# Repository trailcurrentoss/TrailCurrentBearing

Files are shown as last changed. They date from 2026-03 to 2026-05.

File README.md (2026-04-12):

# TrailCurrent Bearing

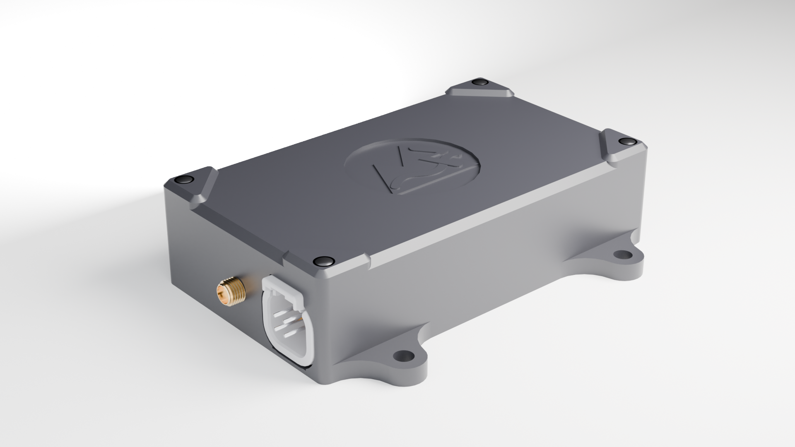
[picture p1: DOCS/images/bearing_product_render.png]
TrailCurrent Bearing


GNSS (Global Navigation Satellite System) module for precise positioning, timing, and navigation. Part of the [TrailCurrent](https://trailcurrent.com) open-source vehicle platform.

## Project Overview

TrailCurrent Bearing is a standalone GNSS module that reads data from a DFRobot Gravity GNSS receiver via I2C and distributes it over the CAN bus for other modules to consume.

**Example Use Cases:**
- Digital clocks with precise time synchronization
- Navigation and geolocation devices
- Geospatial macros that control devices based on pinned locations
- Vehicle tracking and positioning systems

## Hardware Overview

- **Microcontroller:** ESP32-S3 (Waveshare ESP32-S3-RS485-CAN board)
- **GNSS Receiver:** DFRobot Gravity GNSS (I2C, multi-constellation)
- **CAN Bus:** 500 kbps via TWAI driver (GPIO 15 TX, GPIO 16 RX)
- **I2C:** GPIO 1 SDA, GPIO 2 SCL
- **Flash:** 4 MB with dual OTA partitions

### Components

- DFRobot Gravity GNSS module (GPS + BeiDou + GLONASS)
- Waveshare ESP32-S3-RS485-CAN module
- JST XH connectors for power and signal distribution

### KiCAD Library Dependencies

This project uses the consolidated [TrailCurrentKiCADLibraries](https://github.com/trailcurrentoss/TrailCurrentKiCADLibraries).

**Setup:**

```bash
# Clone the library
git clone git@github.com:trailcurrentoss/TrailCurrentKiCADLibraries.git

# Set environment variables (add to ~/.bashrc or ~/.zshrc)
export TRAILCURRENT_SYMBOL_DIR="/path/to/TrailCurrentKiCADLibraries/symbols"
export TRAILCURRENT_FOOTPRINT_DIR="/path/to/TrailCurrentKiCADLibraries/footprints"
export TRAILCURRENT_3DMODEL_DIR="/path/to/TrailCurrentKiCADLibraries/3d_models"
```

See [KICAD_ENVIRONMENT_SETUP.md](https://github.com/trailcurrentoss/TrailCurrentKiCADLibraries/blob/main/KICAD_ENVIRONMENT_SETUP.md) for detailed setup instructions.

## Firmware

Built with ESP-IDF (v5.5.x). Pure C, no Arduino framework.

### Prerequisites

```bash
# Install ESP-IDF (one-time setup)
# See https://docs.espressif.com/projects/esp-idf/en/stable/esp32/get-started/

# Source the ESP-IDF environment
source ~/esp/v5.5.2/esp-idf/export.sh
```

### Build and Flash

```bash
idf.py set-target esp32s3
idf.py build
idf.py -p /dev/ttyACM0 flash monitor
```

### Release Binaries

The firmware produces two binary types for different deployment methods:

| Binary | Purpose | How it's used |
|---|---|---|
| `bearing.bin` | App-only image | OTA updates via Headwaters (`esp_ota_write` validates the app header) |
| `bearing_merged.bin` | Full flash image (bootloader + partition table + OTA data + app) | Web flasher (writes entire flash at offset 0x0) |

After building, run the merge script to create both:

```bash
idf.py build
./merge.sh
```

Attach **both** files to each GitHub release. The merged binary cannot be used for OTA — `esp_ota_end()` validates an app image header, and the merged binary starts with the bootloader, which would fail validation.

### OTA Firmware Update

Firmware can be updated over-the-air via the CAN bus trigger protocol:

1. Send CAN ID `0x00` with the target device's last 3 MAC bytes
2. The device joins WiFi (credentials must be provisioned first) and starts an HTTP server
3. Upload the **app-only** firmware binary:

```bash
curl -X POST http://esp32-XXYYZZ.local/ota --data-binary @build/bearing.bin
```

The device writes to the inactive OTA partition and reboots with the new firmware. If the upload fails or times out (3 minutes), the device returns to normal operation.

### mDNS Self-Discovery

When CAN ID `0x02` is broadcast (typically by the Headwaters controller), all modules with WiFi credentials join the network and advertise themselves via mDNS:

- **Service:** `_trailcurrent._tcp`
- **TXT Records:**
  - `type=bearing` — module type
  - `canid=0x06` — primary CAN status message ID
  - `fw=<version>` — firmware version

The Headwaters controller queries mDNS to discover all online modules, then confirms each via `GET /discovery/confirm`. Modules disconnect from WiFi and return to CAN-only operation after confirmation or a 3-minute timeout.

## CAN Bus Protocol

All messages use standard (11-bit) identifiers at 500 kbps.

### Graceful Node Management

The CAN bus uses a TX_ACTIVE / TX_PROBING state machine that allows nodes to enter and leave the bus without impacting other nodes:

- **TX_ACTIVE:** Normal operation at 30 Hz. If 3 consecutive TX failures occur (no ACK from peers), transitions to TX_PROBING.
- **TX_PROBING:** Sends a single status message every 2 seconds. When a peer ACKs a transmission or incoming RX data is detected, transitions back to TX_ACTIVE.

This means unplugging a module causes it to gracefully back off, and plugging it back in resumes full-rate communication automatically with zero configuration.

### TX Messages (GNSS Data)

| ID | Name | DLC | Format |
|----|---|-----|---|
| `0x06` | DateTime | 7 | `[year_H, year_L, month, day, hour, minute, second]` |
| `0x07` | SatSpeedCourse | 6 | `[satellites, speed_H, speed_L, course_H, course_L, gnss_mode]` |
| `0x08` | Altitude | 4 | `[alt_3, alt_2, alt_1, alt_0]` — altitude in meters * 100 |
| `0x09` | LatLon | 8 | `[lat_sign, lat_2, lat_1, lat_0, lon_sign, lon_2, lon_1, lon_0]` — degrees * 10000 |

**Encoding details:**
- **Speed:** knots * 100 (uint16, big-endian)
- **Course:** degrees * 10 (uint16, big-endian, rounded)
- **Altitude:** meters * 100 (uint32, big-endian)
- **Lat/Lon:** sign byte (0=positive, 1=negative) + 24-bit scaled value (degrees * 10000)

### RX Messages (Control)

| ID | Name | Purpose |
|----|---|---|
| `0x00` | OTA Trigger | `[mac0, mac1, mac2]` — target device by last 3 MAC bytes |
| `0x01` | WiFi Config | Chunked credential provisioning (see below) |
| `0x02` | Discovery | Broadcast trigger for mDNS self-discovery |
| `0x04` | Version Report | Sent on boot: `[mac3, mac4, mac5, major, minor, patch]` — reports running firmware version to Headwaters |

### WiFi Credential Provisioning (CAN ID 0x01)

WiFi credentials are sent in 6-byte chunks over CAN:

1. **Start:** `[0x01, ssid_len, pass_len, ssid_chunks, pass_chunks]`
2. **SSID chunks:** `[0x02, chunk_index, byte0..byte5]`
3. **Password chunks:** `[0x03, chunk_index, byte0..byte5]`
4. **End:** `[0x04, xor_checksum]`

Each chunk carries up to 6 bytes. A 5-second timeout resets reception if a chunk is missed.

## GNSS Modes

The DFRobot Gravity receiver supports multiple satellite constellation configurations:

| Mode | Constellations |
|---|---|
| 1 | GPS only |
| 2 | BeiDou only |
| 3 | GPS + BeiDou |
| 4 | GLONASS only |
| 5 | GPS + GLONASS |
| 6 | BeiDou + GLONASS |
| 7 | GPS + BeiDou + GLONASS (default) |

## Project Structure

```
main/                       # ESP-IDF firmware
├── main.c                  # GNSS polling, CAN TX/RX with state machine
├── gnss.h / gnss.c         # DFRobot GNSS I2C driver
├── ota.h / ota.c           # OTA updates & WiFi provisioning
├── discovery.h / discovery.c  # mDNS auto-discovery
├── CMakeLists.txt          # Build config
└── idf_component.yml       # Managed dependencies (mdns)

EDA/                        # KiCAD hardware design
├── trailcurrent-gps-module.kicad_pro
├── trailcurrent-gps-module.kicad_sch  # Root schematic (5 sheets)
├── trailcurrent-gps-module.kicad_pcb
├── mcu.kicad_sch           # MCU subsystem
├── power.kicad_sch         # Power management
├── can.kicad_sch           # CAN interface
└── connectivity.kicad_sch  # GNSS interface

CAD/                        # FreeCAD housing / 3D prints
partitions.csv              # Dual OTA partition table
sdkconfig.defaults          # Build defaults
```

## Manufacturing

- **PCB Files:** Ready for fabrication via standard PCB services (JLCPCB, OSH Park, etc.)
- **BOM Generation:** Export BOM from KiCAD schematic (Tools > Generate BOM)
- **JLCPCB Assembly:** See [BOM_ASSEMBLY_WORKFLOW.md](https://github.com/trailcurrentoss/TrailCurrentKiCADLibraries/blob/main/BOM_ASSEMBLY_WORKFLOW.md)

## License

MIT License - See LICENSE file for details

This is open source hardware. You are free to use, modify, and distribute these designs for personal or commercial purposes.

## Contributing

Improvements and contributions are welcome! Please submit issues or pull requests to the main repository.

## Support

For questions about:
- **KiCAD setup:** See [KICAD_ENVIRONMENT_SETUP.md](https://github.com/trailcurrentoss/TrailCurrentKiCADLibraries/blob/main/KICAD_ENVIRONMENT_SETUP.md)
- **Library consolidation:** See [CONNECTOR_CONSOLIDATION_SUMMARY.md](https://github.com/trailcurrentoss/TrailCurrentKiCADLibraries/blob/main/CONNECTOR_CONSOLIDATION_SUMMARY.md)
- **Assembly workflow:** See [BOM_ASSEMBLY_WORKFLOW.md](https://github.com/trailcurrentoss/TrailCurrentKiCADLibraries/blob/main/BOM_ASSEMBLY_WORKFLOW.md)

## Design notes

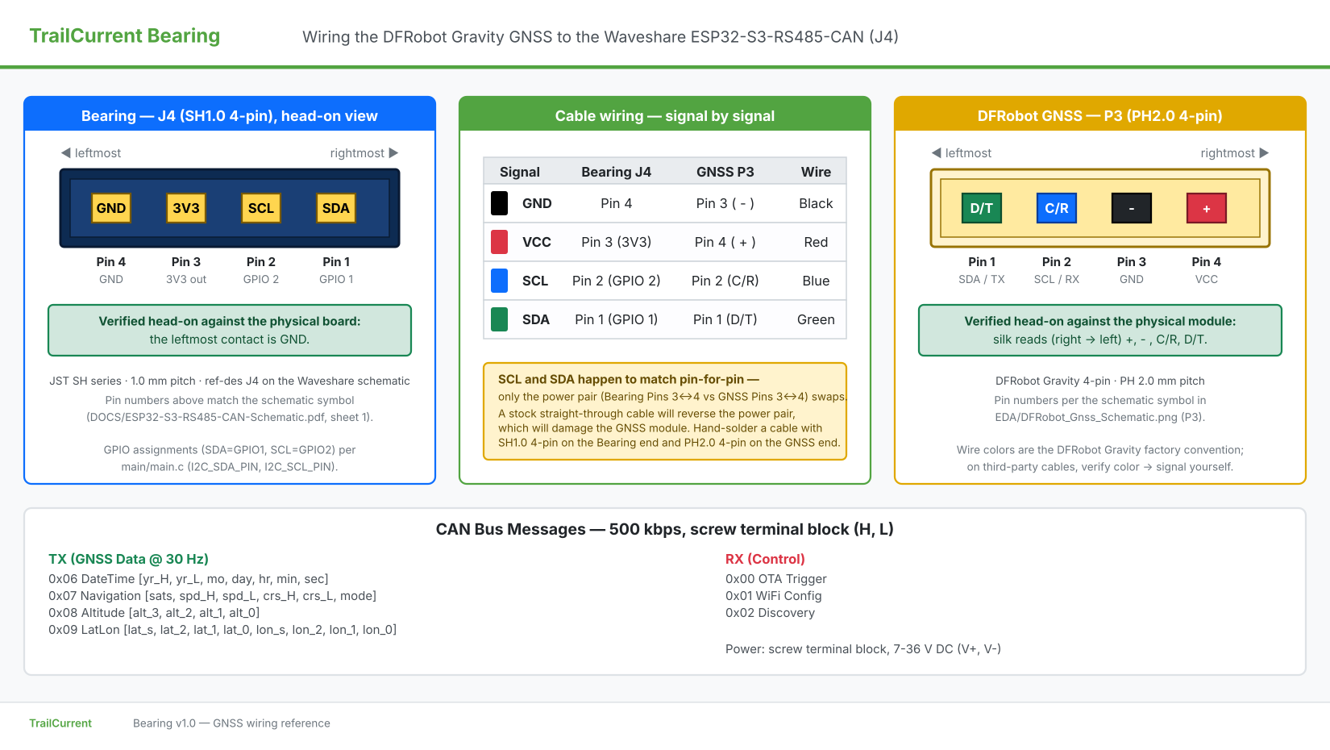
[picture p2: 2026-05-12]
DOCS/bearing-pinout.png

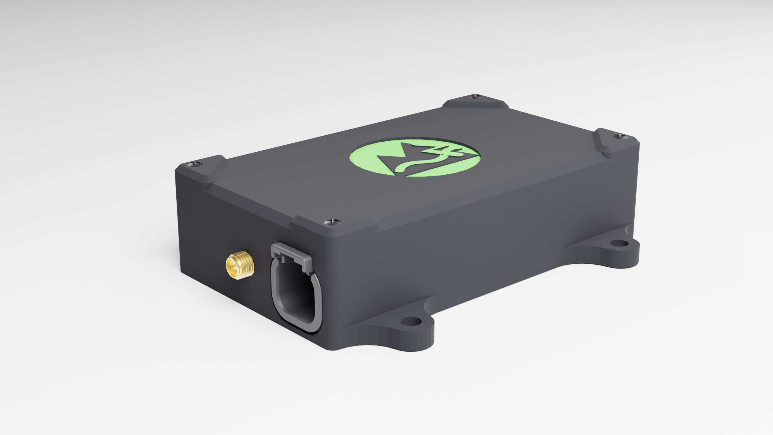
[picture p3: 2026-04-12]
CAD/TrailCurrentBearingRender.png

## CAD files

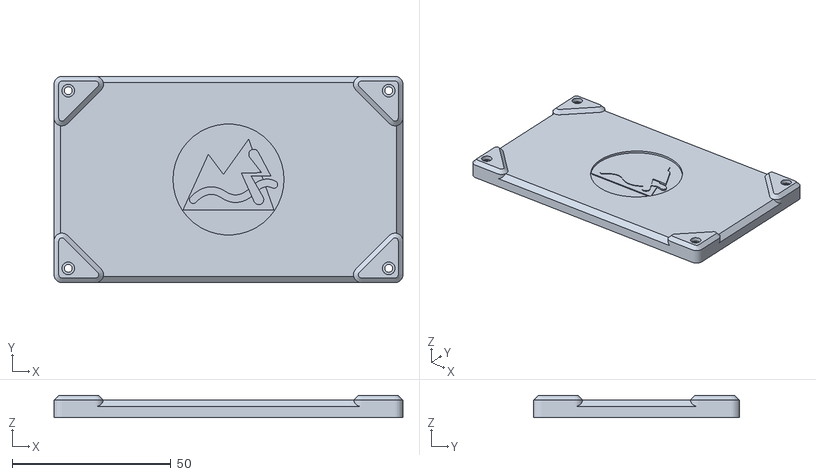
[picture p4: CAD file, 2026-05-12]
CAD/BodyCaseCoverV4.stl
110.0 x 65.0 x 7.00

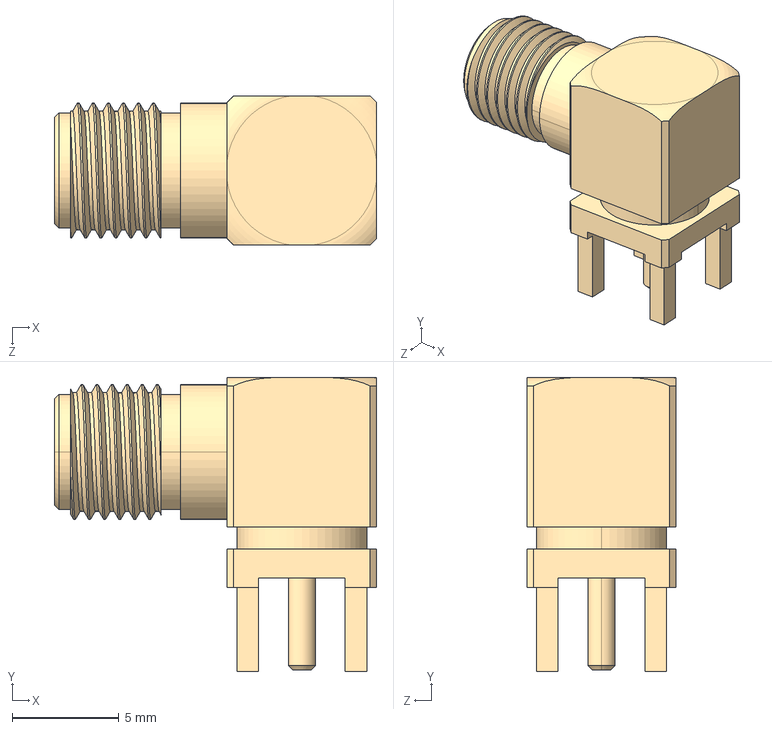
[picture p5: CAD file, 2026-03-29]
CAD/SMA-J-P-H-RA-TH1--3DModel-STEP-269445/SMA-J-P-H-RA-TH1--3DModel-STEP-269445.STEP
15.1 x 13.8 x 7.00 mm

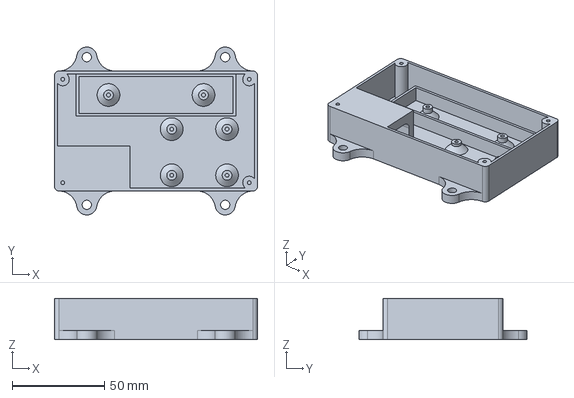
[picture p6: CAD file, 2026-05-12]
CAD/TrailCurrentBearingHousing.FCStd
110.0 x 91.0 x 22.2 mm

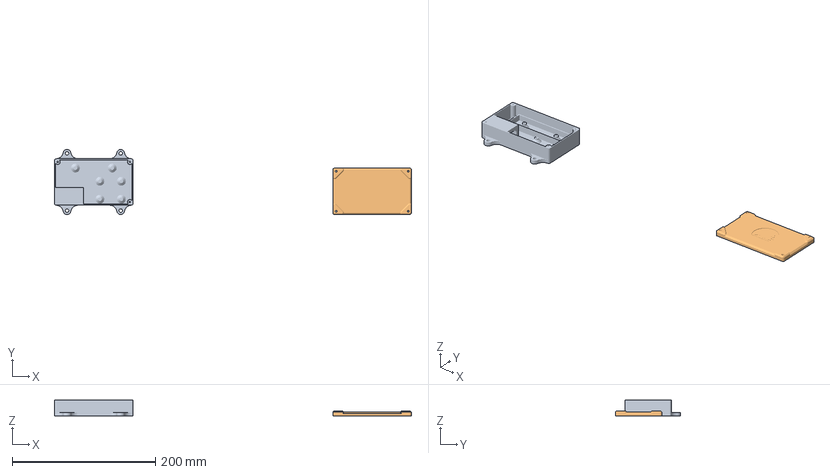
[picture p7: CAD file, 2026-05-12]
CAD/TrailCurrentBearingCase.3mf
499.2 x 90.9 x 22.2 mm
BodyCaseBottomV2.stl
BodyCaseCoverV4.stl

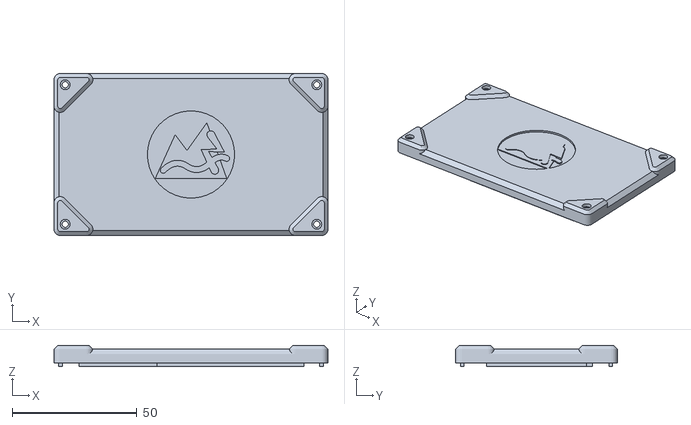
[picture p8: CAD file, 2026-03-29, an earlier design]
CAD/BodyCaseCoverV2.stl
110.0 x 65.0 x 8.50

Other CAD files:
CAD/BodyCaseBottomV2.stl
CAD/BodyCaseCoverV1.stl
CAD/TrailCurrentBearingRender.blend

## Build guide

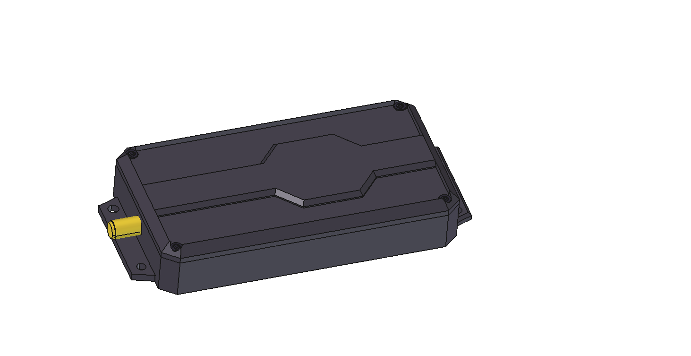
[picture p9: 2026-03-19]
DOCS/images/bearing_assembled.png

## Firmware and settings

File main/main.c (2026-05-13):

#include <stdio.h>
#include <stdbool.h>
#include <string.h>
#include "freertos/FreeRTOS.h"
#include "freertos/task.h"
#include "driver/twai.h"
#include "esp_log.h"
#include "esp_timer.h"
#include "can_common.h"
#include "wifi_config.h"
#include "ota.h"
#include "discovery.h"
#include "gnss.h"

static const char *TAG = "bearing";

// Waveshare ESP32-S3-RS485-CAN pin assignments
#define CAN_TX_PIN   15
#define CAN_RX_PIN   16
#define I2C_SDA_PIN  1
#define I2C_SCL_PIN  2

// CAN message identifiers (TX — GNSS data)
#define CAN_ID_DATETIME   0x06
#define CAN_ID_SAT_SPEED  0x07
#define CAN_ID_ALTITUDE   0x08
#define CAN_ID_LATLON     0x09

// CAN message identifiers (RX — control triggers)
#define CAN_ID_OTA              0x00
#define CAN_ID_WIFI_CONFIG      0x01
#define CAN_ID_DISCOVERY        0x02

// CAN transmit timing
#define CAN_STATUS_PERIOD_MS   33    // ~30 Hz normal rate
#define TX_PROBE_INTERVAL_MS   2000  // slow probe when no peers

// GNSS poll interval
#define GNSS_POLL_MS  100

// ---------------------------------------------------------------------------
// Shared GNSS data (written by main task, read by CAN task)
// volatile prevents single-access reordering but does NOT make the multi-field
// snapshot atomic — a spinlock guards the whole group so the CAN task never
// captures torn values across a GNSS update (e.g. mixed minute/second on the
// rollover that made the time appear to "jump").
// ---------------------------------------------------------------------------

static portMUX_TYPE g_gnss_mux = portMUX_INITIALIZER_UNLOCKED;
static uint16_t g_year;
static uint8_t  g_month, g_day, g_hour, g_minute, g_second;
static float    g_latitude, g_longitude;
static double   g_altitude, g_speed, g_course;
static uint8_t  g_satellites, g_gnss_mode;

// ---------------------------------------------------------------------------
// CAN data encoding helpers
// ---------------------------------------------------------------------------

static void encode_lat_lon(float value, uint8_t out[4])
{
    out[0] = (value < 0) ? 1 : 0;
    if (value < 0) value = -value;
    uint32_t scaled = (uint32_t)(value * 10000.0f + 0.5f);
    out[1] = (scaled >> 16) & 0xFF;
    out[2] = (scaled >> 8) & 0xFF;
    out[3] = scaled & 0xFF;
}

// ---------------------------------------------------------------------------
// TWAI (CAN) task — runs independently from I2C polling
// ---------------------------------------------------------------------------


static void twai_task(void *arg)
{
    // Configure alerts BEFORE any bus activity so no error transitions are missed.
    twai_reconfigure_alerts(CAN_COMMON_ALERTS, NULL);

    // Alerts armed — version broadcast TX failure is caught by the state machine.
    can_common_version_broadcast();

    typedef enum { TX_ACTIVE, TX_PROBING } tx_state_t;
    bool bus_off = false;
    tx_state_t tx_state = TX_ACTIVE;
    int tx_fail_count = 0;
    const int TX_FAIL_THRESHOLD = 3;
    int64_t last_tx_us = 0;
    const int64_t tx_period_us = CAN_STATUS_PERIOD_MS * 1000LL;
    const int64_t tx_probe_period_us = TX_PROBE_INTERVAL_MS * 1000LL;

    while (1) {
        uint32_t triggered;
        twai_read_alerts(&triggered, pdMS_TO_TICKS(CAN_STATUS_PERIOD_MS));

        // Bus-off recovery
        if (triggered & TWAI_ALERT_BUS_OFF) {
            ESP_LOGE(TAG, "TWAI bus-off, initiating recovery");
            bus_off = true;
            twai_initiate_recovery();
            // No continue — fall through so RX_DATA in the same poll is still processed.
        }

        if (triggered & TWAI_ALERT_BUS_RECOVERED) {
            ESP_LOGI(TAG, "TWAI bus recovered, restarting");
            twai_start();
            bus_off = false;
            tx_fail_count = 0;
            tx_state = TX_PROBING;
        }

        if (triggered & TWAI_ALERT_ERR_PASS) {
            ESP_LOGW(TAG, "TWAI error passive (no peers ACKing?)");
        }

        // TX failure tracking — graceful backoff when no peers on bus
        if (triggered & TWAI_ALERT_TX_FAILED) {
            if (tx_state == TX_ACTIVE) {
                tx_fail_count++;
                if (tx_fail_count >= TX_FAIL_THRESHOLD) {
                    tx_state = TX_PROBING;
                    ESP_LOGW(TAG, "TWAI no peers detected, entering slow probe");
                }
            }
        }

        // TX success — peer detected, resume normal rate
        if (triggered & TWAI_ALERT_TX_SUCCESS) {
            if (tx_state == TX_PROBING) {
                tx_state = TX_ACTIVE;
                tx_fail_count = 0;
                can_common_version_broadcast();
                ESP_LOGI(TAG, "TWAI probe ACK'd, peer detected, resuming normal TX");
            }
            tx_fail_count = 0;
        }

        // Drain received messages and dispatch
        if (triggered & TWAI_ALERT_RX_DATA) {
            if (tx_state == TX_PROBING) {
                tx_state = TX_ACTIVE;
                tx_fail_count = 0;
                can_common_version_broadcast();
                ESP_LOGI(TAG, "TWAI peer detected via RX, resuming normal TX");
            }
            twai_message_t msg;
            while (twai_receive(&msg, 0) == ESP_OK) {
                if (msg.rtr) continue;

                switch (msg.identifier) {
                case CAN_ID_OTA:
                    ota_handle_trigger(msg.data, msg.data_length_code);
                    break;
                case CAN_ID_WIFI_CONFIG:
                    wifi_config_handle_can(msg.data, msg.data_length_code);
                    break;
                case CAN_ID_DISCOVERY:
                    discovery_handle_trigger();
                    break;
                default:
                    break;
                }
            }
        }

        // Check wifi config timeout
        wifi_config_check_timeout();

        // Periodic transmit (skip if bus is down)
        int64_t now_us = esp_timer_get_time();
        int64_t effective_period = (tx_state == TX_PROBING) ? tx_probe_period_us : tx_period_us;
        if (!bus_off && (now_us - last_tx_us >= effective_period)) {
            last_tx_us = now_us;

            // Snapshot shared GNSS data atomically — without the spinlock the
            // CAN task could read e.g. minute from one sample and second from
            // the next, producing jumps on every rollover boundary.
            uint16_t year;
            uint8_t month, day, hour, minute, second;
            float lat, lon;
            double alt, spd, crs;
            uint8_t sats, mode;
            taskENTER_CRITICAL(&g_gnss_mux);
            year = g_year;
            month = g_month; day = g_day;
            hour = g_hour; minute = g_minute; second = g_second;
            lat = g_latitude; lon = g_longitude;
            alt = g_altitude; spd = g_speed; crs = g_course;
            sats = g_satellites; mode = g_gnss_mode;
            taskEXIT_CRITICAL(&g_gnss_mux);

            // 0x06: DateTime [year_h, year_l, month, day, hour, minute, second]
            twai_message_t m_dt = {
                .identifier = CAN_ID_DATETIME,
                .data_length_code = 7,
                .data = {
                    (year >> 8) & 0xFF, year & 0xFF,
                    month, day, hour, minute, second
                }
            };

            // 0x07: [satellites, speed_h, speed_l, course_h, course_l, gnss_mode]
            uint16_t speed_scaled = (uint16_t)(spd * 100.0);
            uint16_t course_scaled = (uint16_t)(crs * 10.0 + 0.5);
            twai_message_t m_nav = {
                .identifier = CAN_ID_SAT_SPEED,
                .data_length_code = 6,
                .data = {
                    sats,
                    (speed_scaled >> 8) & 0xFF, speed_scaled & 0xFF,
                    (course_scaled >> 8) & 0xFF, course_scaled & 0xFF,
                    mode
                }
            };

            // 0x08: [alt_3, alt_2, alt_1, alt_0] (altitude * 100)
            uint32_t alt_scaled = (uint32_t)(alt * 100.0);
            twai_message_t m_alt = {
                .identifier = CAN_ID_ALTITUDE,
                .data_length_code = 4,
                .data = {
                    (alt_scaled >> 24) & 0xFF,
                    (alt_scaled >> 16) & 0xFF,
                    (alt_scaled >> 8) & 0xFF,
                    alt_scaled & 0xFF
                }
            };

            // 0x09: [lat_sign, lat_2, lat_1, lat_0, lon_sign, lon_2, lon_1, lon_0]
            uint8_t lat_enc[4], lon_enc[4];
            encode_lat_lon(lat, lat_enc);
            encode_lat_lon(lon, lon_enc);
            twai_message_t m_pos = {
                .identifier = CAN_ID_LATLON,
                .data_length_code = 8,
                .data = {
                    lat_enc[0], lat_enc[1], lat_enc[2], lat_enc[3],
                    lon_enc[0], lon_enc[1], lon_enc[2], lon_enc[3]
                }
            };

            twai_transmit(&m_dt, 0);
            twai_transmit(&m_nav, 0);
            twai_transmit(&m_alt, 0);
            twai_transmit(&m_pos, 0);
        }
    }
}

// ---------------------------------------------------------------------------
// Main application
// ---------------------------------------------------------------------------

void app_main(void)
{
    // Initialize WiFi config (NVS, hostname, credentials)
    wifi_config_init();
    char ssid[33], password[64];
    wifi_config_load(ssid, sizeof(ssid), password, sizeof(password));

    ota_init();
    discovery_init();

    ESP_LOGI(TAG, "=== TrailCurrent Bearing ===");
    ESP_LOGI(TAG, "Hostname: %s", wifi_config_get_hostname());

    // CAN runs in its own task — start before GNSS so discovery/OTA work
    // even while waiting for the GNSS module
    ESP_ERROR_CHECK(can_common_init(CAN_TX_PIN, CAN_RX_PIN));
    xTaskCreatePinnedToCore(twai_task, "twai", 4096, NULL, 5, NULL, 1);

    // Initialize DFRobot GNSS module via I2C
    while (gnss_init(I2C_SDA_PIN, I2C_SCL_PIN) != ESP_OK) {
        ESP_LOGW(TAG, "GNSS module not found, retrying...");
        vTaskDelay(pdMS_TO_TICKS(1000));
    }
    gnss_enable_power();
    gnss_set_mode(GNSS_MODE_GPS_BEIDOU_GLONASS);
    gnss_set_rgb_on();

    // Main task: poll GNSS data via I2C
    uint32_t log_counter = 0;
    while (1) {
        gnss_data_t data;
        if (gnss_read(&data) == ESP_OK) {
            bool date_valid =
                data.year  >= 2025 && data.year  <= 2099 &&
                data.month >= 1    && data.month <= 12 &&
                data.day   >= 1    && data.day   <= 31 &&
                data.hour  <= 23 &&
                data.minute <= 59 &&
                data.second <= 60;

            if (++log_counter >= (1000 / GNSS_POLL_MS)) {
                log_counter = 0;
                ESP_LOGI(TAG, "GNSS raw: %04u-%02u-%02u %02u:%02u:%02u  sats=%u  date_valid=%d",
                         data.year, data.month, data.day,
                         data.hour, data.minute, data.second,
                         data.satellites, date_valid);
            }
            taskENTER_CRITICAL(&g_gnss_mux);
            if (date_valid) {
                g_year      = data.year;
                g_month     = data.month;
                g_day       = data.day;
                g_hour      = data.hour;
                g_minute    = data.minute;
                g_second    = data.second;
            }
            g_latitude  = data.latitude;
            g_longitude = data.longitude;
            g_altitude  = data.altitude;
            g_satellites = data.satellites;
            g_speed     = data.speed;
            g_course    = data.course;
            g_gnss_mode = data.gnss_mode;
            taskEXIT_CRITICAL(&g_gnss_mux);
        }
        vTaskDelay(pdMS_TO_TICKS(GNSS_POLL_MS));
    }
}

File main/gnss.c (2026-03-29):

#include "gnss.h"

#include <string.h>
#include "driver/i2c_master.h"
#include "esp_log.h"

static const char *TAG = "gnss";

// DFRobot Gravity GNSS I2C address
#define GNSS_I2C_ADDR  0x20

// Data register map (from DFRobot_GNSS library)
//
//  Reg  Name           Description
//  ---  ----           -----------
//   0   I2C_YEAR_H     Year high byte
//   1   I2C_YEAR_L     Year low byte
//   2   I2C_MONTH      Month
//   3   I2C_DATE       Day
//   4   I2C_HOUR       Hour (UTC)
//   5   I2C_MINUTE     Minute
//   6   I2C_SECOND     Second
//   7   I2C_LAT_1      Latitude degrees
//   8   I2C_LAT_2      Latitude whole minutes
//   9   I2C_LAT_X_24   Latitude fractional minutes [23:16]
//  10   I2C_LAT_X_16   Latitude fractional minutes [15:8]
//  11   I2C_LAT_X_8    Latitude fractional minutes [7:0]
//  12   I2C_LON_DIS    ** Longitude direction ** (ASCII 'E'/'W')
//  13   I2C_LON_1      Longitude degrees
//  14   I2C_LON_2      Longitude whole minutes
//  15   I2C_LON_X_24   Longitude fractional minutes [23:16]
//  16   I2C_LON_X_16   Longitude fractional minutes [15:8]
//  17   I2C_LON_X_8    Longitude fractional minutes [7:0]
//  18   I2C_LAT_DIS    ** Latitude direction ** (ASCII 'N'/'S')
//  19   I2C_USE_STAR   Number of satellites used
//  20   I2C_ALT_H      Altitude high byte (bit 7 = sign flag)
//  21   I2C_ALT_L      Altitude low byte
//  22   I2C_ALT_X      Altitude fractional (hundredths)
//  23   I2C_SOG_H      Speed over ground high (bit 7 = sign flag)
//  24   I2C_SOG_L      Speed over ground low
//  25   I2C_SOG_X      SOG fractional (hundredths)
//  26   I2C_COG_H      Course over ground high (bit 7 = sign flag)
//  27   I2C_COG_L      COG low
//  28   I2C_COG_X      COG fractional (hundredths)
//
// Note: direction registers are NOT adjacent to their coordinate data.
// Reg 12 is LONGITUDE direction, reg 18 is LATITUDE direction.

#define REG_YEAR_H     0
#define REG_LAT_1      7
#define REG_LON_DIS    12   // longitude direction (ASCII 'E' or 'W')
#define REG_LON_1      13
#define REG_LAT_DIS    18   // latitude direction (ASCII 'N' or 'S')
#define REG_USE_STAR   19
#define REG_ALT_H      20
#define REG_SOG_H      23
#define REG_COG_H      26
#define REG_DATA_LEN   29   // registers 0-28

// Configuration registers
#define REG_GNSS_MODE  34   // constellation mode (1-7)
#define REG_SLEEP_MODE 35   // power control (0x00 = enable, 0x01 = disable)
#define REG_RGB_MODE   36   // RGB LED (0x05 = on, 0x02 = off)

static i2c_master_bus_handle_t s_bus = NULL;
static i2c_master_dev_handle_t s_dev = NULL;

static esp_err_t gnss_write_reg(uint8_t reg, uint8_t val)
{
    uint8_t buf[2] = { reg, val };
    return i2c_master_transmit(s_dev, buf, 2, -1);
}

static esp_err_t gnss_read_regs(uint8_t start_reg, uint8_t *buf, size_t len)
{
    return i2c_master_transmit_receive(s_dev, &start_reg, 1, buf, len, -1);
}

static void gnss_cleanup(void)
{
    if (s_dev) {
        i2c_master_bus_rm_device(s_dev);
        s_dev = NULL;
    }
    if (s_bus) {
        i2c_del_master_bus(s_bus);
        s_bus = NULL;
    }
}

esp_err_t gnss_init(int sda_pin, int scl_pin)
{
    // Clean up any prior failed init
    gnss_cleanup();

    i2c_master_bus_config_t bus_cfg = {
        .clk_source = I2C_CLK_SRC_DEFAULT,
        .i2c_port = I2C_NUM_0,
        .scl_io_num = scl_pin,
        .sda_io_num = sda_pin,
        .glitch_ignore_cnt = 7,
        .flags.enable_internal_pullup = true,
    };
    esp_err_t err = i2c_new_master_bus(&bus_cfg, &s_bus);
    if (err != ESP_OK) {
        ESP_LOGE(TAG, "Failed to create I2C bus: %s", esp_err_to_name(err));
        s_bus = NULL;
        return err;
    }

    i2c_device_config_t dev_cfg = {
        .dev_addr_length = I2C_ADDR_BIT_LEN_7,
        .device_address = GNSS_I2C_ADDR,
        .scl_speed_hz = 100000,
    };
    err = i2c_master_bus_add_device(s_bus, &dev_cfg, &s_dev);
    if (err != ESP_OK) {
        ESP_LOGE(TAG, "Failed to add GNSS device: %s", esp_err_to_name(err));
        gnss_cleanup();
        return err;
    }

    // Probe the device with a small read
    uint8_t probe;
    err = gnss_read_regs(0x00, &probe, 1);
    if (err != ESP_OK) {
        ESP_LOGE(TAG, "GNSS device not found at 0x%02X", GNSS_I2C_ADDR);
        gnss_cleanup();
        return ESP_FAIL;
    }

    ESP_LOGI(TAG, "DFRobot GNSS module found at 0x%02X", GNSS_I2C_ADDR);
    return ESP_OK;
}

esp_err_t gnss_enable_power(void)
{
    return gnss_write_reg(REG_SLEEP_MODE, 0x00);
}

esp_err_t gnss_set_mode(uint8_t mode)
{
    ESP_LOGI(TAG, "Setting GNSS constellation mode: %d", mode);
    return gnss_write_reg(REG_GNSS_MODE, mode);
}

esp_err_t gnss_set_rgb_on(void)
{
    return gnss_write_reg(REG_RGB_MODE, 0x05);
}

esp_err_t gnss_set_rgb_off(void)
{
    return gnss_write_reg(REG_RGB_MODE, 0x02);
}

esp_err_t gnss_read(gnss_data_t *data)
{
    uint8_t buf[REG_DATA_LEN];
    esp_err_t err = gnss_read_regs(REG_YEAR_H, buf, REG_DATA_LEN);
    if (err != ESP_OK) {
        return err;
    }

    // Time and date (regs 0-6)
    data->year   = ((uint16_t)buf[0] << 8) | buf[1];
    data->month  = buf[2];
    data->day    = buf[3];
    data->hour   = buf[4];
    data->minute = buf[5];
    data->second = buf[6];

    // Latitude data (regs 7-11), direction at reg 18
    uint8_t lat_dd = buf[7];
    uint8_t lat_mm = buf[8];
    uint32_t lat_frac = ((uint32_t)buf[9] << 16) | ((uint32_t)buf[10] << 8) | buf[11];
    float lat_deg = (float)lat_dd + ((float)lat_mm + (float)lat_frac / 100000.0f) / 60.0f;
    data->latitude = (buf[REG_LAT_DIS] == 'S') ? -lat_deg : lat_deg;

    // Longitude data (regs 13-17), direction at reg 12
    uint8_t lon_dd = buf[13];
    uint8_t lon_mm = buf[14];
    uint32_t lon_frac = ((uint32_t)buf[15] << 16) | ((uint32_t)buf[16] << 8) | buf[17];
    float lon_deg = (float)lon_dd + ((float)lon_mm + (float)lon_frac / 100000.0f) / 60.0f;
    data->longitude = (buf[REG_LON_DIS] == 'W') ? -lon_deg : lon_deg;

    // Satellites (reg 19)
    data->satellites = buf[19];

    // Altitude (regs 20-22): bit 7 of high byte is sign flag, mask it off
    data->altitude = (double)((((uint16_t)buf[20] & 0x7F) << 8) | buf[21]) + (double)buf[22] / 100.0;

    // Speed over ground (regs 23-25): bit 7 of high byte is sign flag
    data->speed = (double)((((uint16_t)buf[23] & 0x7F) << 8) | buf[24]) + (double)buf[25] / 100.0;

    // Course over ground (regs 26-28): bit 7 of high byte is sign flag
    data->course = (double)((((uint16_t)buf[26] & 0x7F) << 8) | buf[27]) + (double)buf[28] / 100.0;

    // Read constellation mode from config register (not in the data block)
    uint8_t mode;
    if (gnss_read_regs(REG_GNSS_MODE, &mode, 1) == ESP_OK) {
        data->gnss_mode = mode;
    } else {
        data->gnss_mode = 0;
    }

    return ESP_OK;
}

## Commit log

2026-03-27 Moved to ESP-IDF
    [partitions.csv]
2026-03-27 Fix bug with lat/long post ESP-IDF migration
    [gnss.c]
2026-03-28 Fixing issue with CAN Bus stops responding when discovery happens
    [main.c]
2026-03-29 Fix for sequence of initalization between GNSS and TWAI
    [main.c]
2026-03-29 Moved to out of the box waveshare esp32s3 board
    [partitions.csv]
2026-03-29 Switched pins to use waveshave cable pins. V1 of case design started
    [TrailCurrentBearingHousing.FCStd]
2026-03-29 Turning status LED on temporarily once validated we'll shut it back off again to conserve power
2026-03-29 Gixed GNSS status not sent over CAN Bus
    [TrailCurrentBearingCase.3mf, TrailCurrentBearingHousing.FCStd]
2026-03-29 Test release for bearing
2026-03-29 Updates to case design and OTA to report version to headwaters on update.
    [TrailCurrentBearingCase.3mf, TrailCurrentBearingHousing.FCStd]
2026-03-29 Removing old case designs
    [BodyCaseCoverV1.stl, TrailCurrentBearingCase.3mf, TrailCurrentGpsModuleCase.3mf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]
2026-03-29 Added assembly with OEM parts to freecad, 3mf updated with cover.
    [BodyCaseCoverV2.stl, SMA-J-P-H-RA-TH1--3DModel-STEP-269445.STEP, TrailCurrentBearingCase.3mf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]
2026-03-30 Fixed discovery not sending the CAN ID based on the firmware
    [TrailCurrentBearingCase.3mf]
2026-03-30 Adding blender render of new case design. Housing deisgn updated to use waveshare
    [TrailCurrentBearingHousing.FCStd, TrailCurrentBearingRender.blend]
2026-04-12 Updated documentation, case design complete, blender animation aded, and documentation updates
    [TrailCurrentBearingHousing.FCStd, TrailCurrentBearingRender.blend]
2026-05-12 Updated documentation and added dual color temporarily to print
    [BodyCaseBottomV2.stl, BodyCaseCoverV3.stl, BodyCaseCoverV4.stl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]
2026-05-13 Changed variables to avoid issues with broadcasting date/time values
    [main.c]
